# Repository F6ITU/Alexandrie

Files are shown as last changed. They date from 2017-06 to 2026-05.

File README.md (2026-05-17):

# Alexandrie

  **Pour plus d'informations, consultez le Wiki associé à cette page**
  **For more information, see the Wiki associated with this page**
  
Kicad files

Control board for Alexiares filter set

This work is protected by the TAPR Open Hardware Licence https://www.tapr.org/ohl.html

Original work by Graham Haddock, KE9H and Phil Harman, VK6APH.

This board supports the SPI "Alexiares" protocol (also called "J16") of 
the original Hermes SDR board designed by the OpenHPSDR group.

As Alexiares was not sold anymore by the TAPR, a new and more "modular" 
design was needed by many hams wishing to play with OpenHPSDR plateforms
(Homebrewed Hermes or Angelia boards, Steve KF7O's Hermes Lite, Red Pitaya 
supporting Pavel Denim's firmware... ) 

Alexandrie is only needed by people using an original 
Hermes Board or a Red Pitaya (via the SPI output)

A specific replacement board (Alexi2C) has been design for 

* Hermes, Angelia, Odyssey2, HiQSDR boards
*  Red Pitaya owners using the I2C output

3D image of the board are stored on this repo

Alexandrie dwn.jpg

Alexandrie up.jpg

Board's dimensions are oversized to fit the 5x10 and 10x10cm 
size of all board of the Hermes project under Kicad: 

AlexI2C

Alexandrie (this one)

Alexiares_Coax_Out

Alexiares_HPF

Alexiares_LPF

Mentor

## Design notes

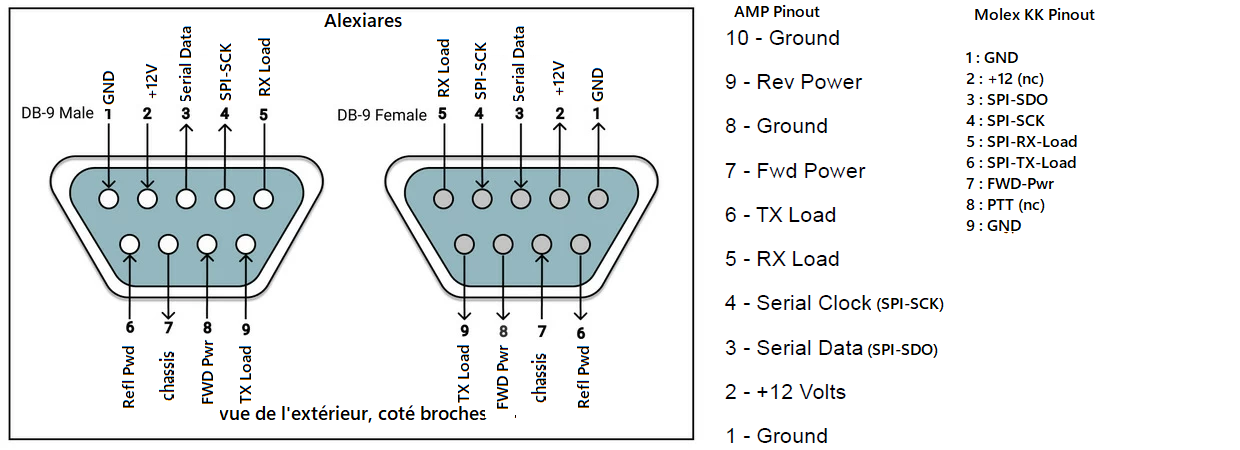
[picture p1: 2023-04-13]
Hermes-Alex_Pinout.png

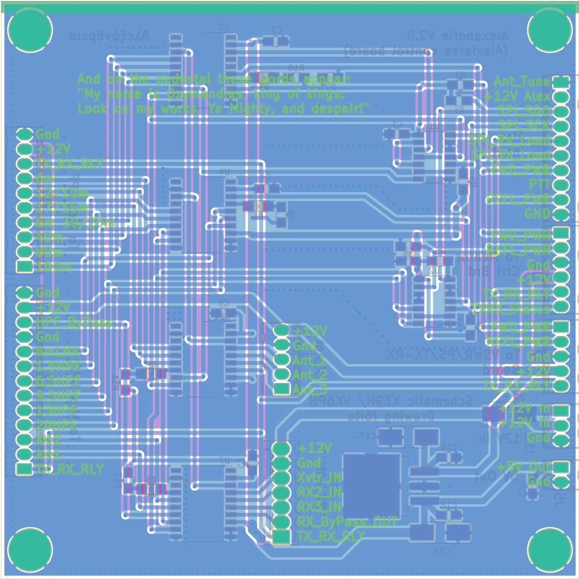
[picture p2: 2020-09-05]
Gerber.png_top_XRAY.png

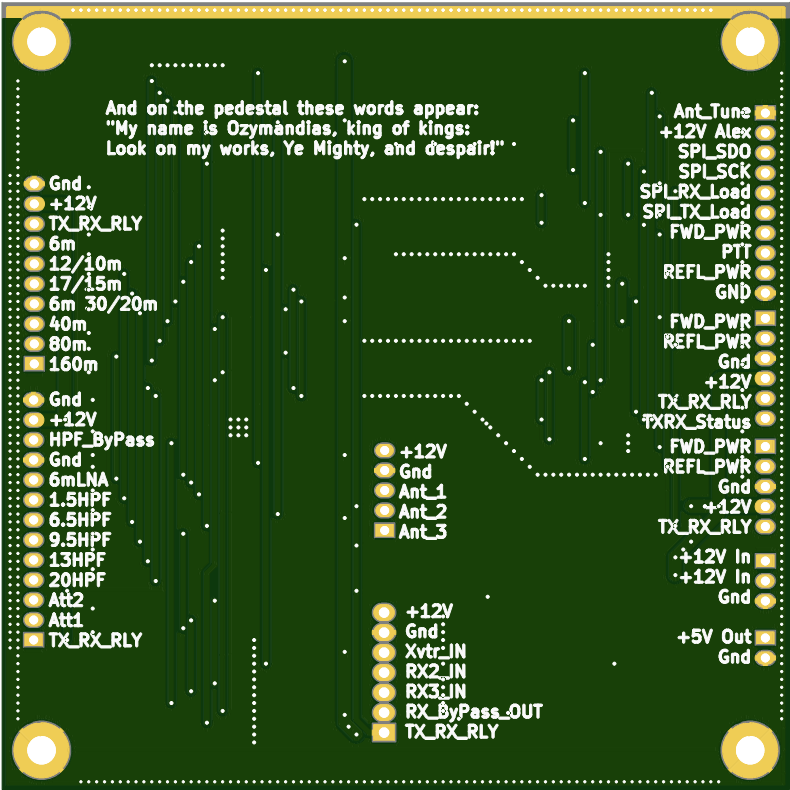
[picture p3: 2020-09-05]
Gerber.png_Combined_Bottom.png

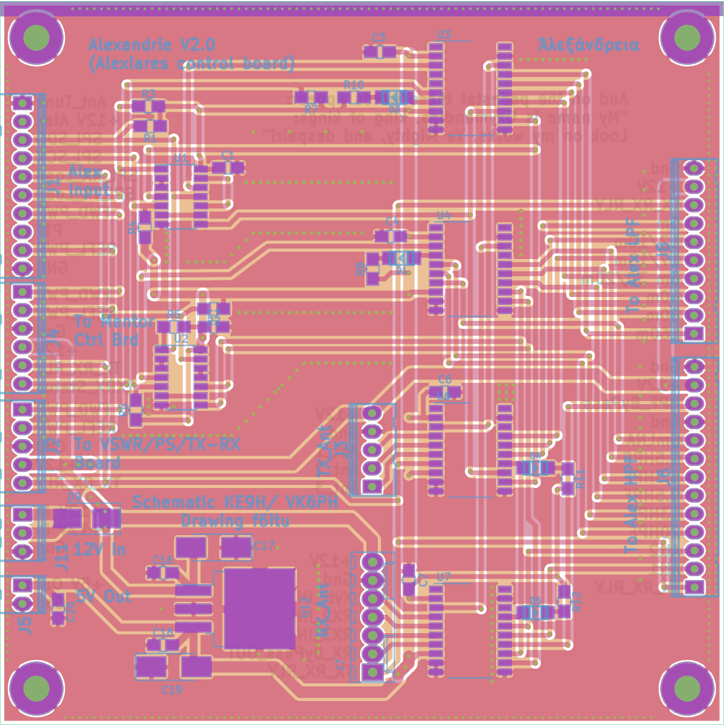
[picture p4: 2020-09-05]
Gerber.png_bottom_XRAY.png

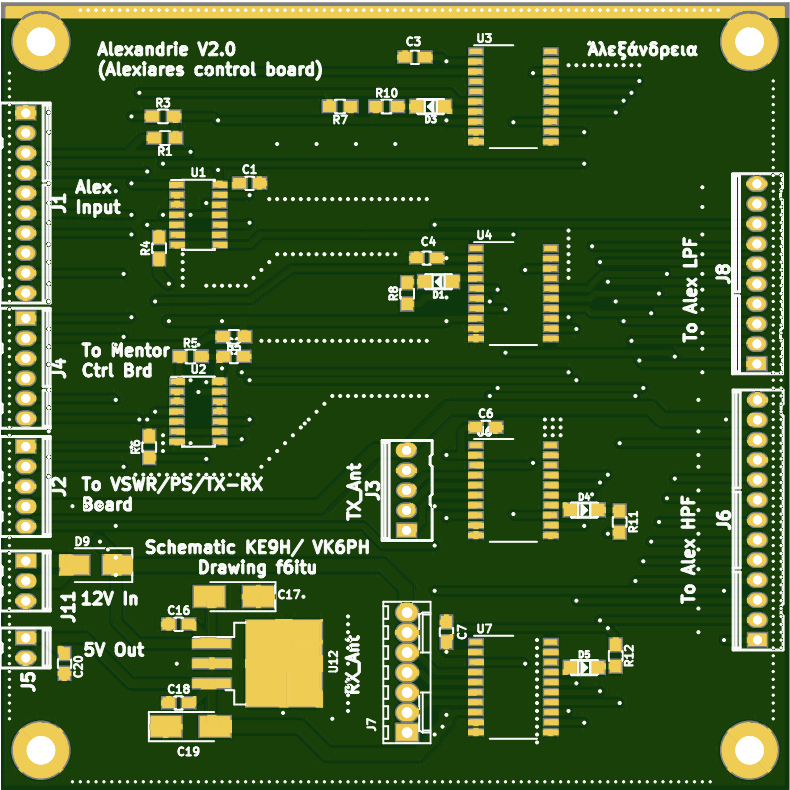
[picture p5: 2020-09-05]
Gerber.png_Combined_Top.png

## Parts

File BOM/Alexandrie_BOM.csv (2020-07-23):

Component Count: | 43
Ref | Value | Footprint | Manufacturer | Vendor | Reference
C1 | 100n | Capacitors_SMD:C_0805_HandSoldering
C2 | 100n | Capacitors_SMD:C_0805_HandSoldering
C3 | 100n | Capacitors_SMD:C_0805_HandSoldering
C4 | 100n | Capacitors_SMD:C_0805_HandSoldering
C6 | 100n | Capacitors_SMD:C_0805_HandSoldering
C7 | 100n | Capacitors_SMD:C_0805_HandSoldering
C16 | 100n | Capacitors_SMD:C_0805_HandSoldering
C17 | 10u | Capacitors_Tantalum_SMD Case-C_EIA-6032-28
C18 | 100n | Capacitors_SMD:C_0805_HandSoldering
C19 | 10u | Capacitors_Tantalum_SMD: Case-C_EIA-6032-28
C20 | 100n | Capacitors_SMD:C_0805_HandSoldering
D1 | LED | smd_leds:Led_1206
D3 | LED | smd_leds:Led_1206
D4 | LED | smd_leds:Led_1206
D5 | LED | smd_leds:Led_1206
D9 | D | Diodes_SMD:D_SMB_Handsoldering | On Semiconductor ss24 | Mouser | 863-SS24T3G
J1 | kk_10 | conn_kk100:kk100_22-23-2101 | Molex KF2510 | eBay | KF2510-10P
J2 | kk_5 | conn_kk100:kk100_22-23-2051 | Molex KF2510 | eBay | KF2510-5P
J3 | kk_5 | conn_kk100:kk100_22-23-2051 | Molex KF2510 | eBay | KF2510-5P
J4 | CONN_01X06 | conn_kk100:kk100_22-23-2061 | Molex KF2510 | eBay | KF2510-6P
J5 | CONN_01X02 | conn_kk100:kk100_22-23-2021 | Molex KF2510 | eBay | KF2510-2P
J6 | CONN_01X13 | conn_kk100:kk100_22-23-2131 | Molex KF2510 | eBay | KF2510-13P
J7 | Conn_01x07 | Connectors_Molex:Molex_KK-6410-07_07x2.54mm_Straight | Molex KF2510 | eBay | KF2510-7P
J8 | kk_10 | conn_kk100:kk100_22-23-2101 | Molex KF2510 | eBay | KF2510-10P
J11 | CONN_01X03 | conn_kk100:kk100_22-23-2031 | Molex KF2510 | eBay | KF2510-13P
R1 | 10k | Resistors_SMD:R_0805_HandSoldering
R2 | 10k | Resistors_SMD:R_0805_HandSoldering
R3 | 10k | Resistors_SMD:R_0805_HandSoldering
R4 | 10k | Resistors_SMD:R_0805_HandSoldering
R5 | 10k | Resistors_SMD:R_0805_HandSoldering
R6 | 10k | Resistors_SMD:R_0805_HandSoldering
R7 | 4k7 | Resistors_SMD:R_0805_HandSoldering
R8 | 1k2 | Resistors_SMD:R_0805_HandSoldering
R10 | 1k2 | Resistors_SMD:R_0805_HandSoldering
R11 | 1k2 | Resistors_SMD:R_0805_HandSoldering
R12 | 1k2 | Resistors_SMD:R_0805_HandSoldering
U1 | 74HCT04 | Housings_SOIC:SOIC-14_3.9x8.7mm_Pitch1.27mm |  | Mouser | MC74HCT04ADR2G
U2 | 74HCT04 | Housings_SOIC:SOIC-14_3.9x8.7mm_Pitch1.27mm |  | Mouser | MC74HCT04ADR2G
U3 | TPIC6B595 | Housings_SOIC:SO-20_12.8x7.5mm_Pitch1.27mm |  | Mouser | 595-TPIC6B595DWR
U4 | TPIC6B595 | Housings_SOIC:SO-20_12.8x7.5mm_Pitch1.27mm |  | Mouser | 595-TPIC6B595DWR
U6 | TPIC6B595 | Housings_SOIC:SO-20_12.8x7.5mm_Pitch1.27mm |  | Mouser | 595-TPIC6B595DWR
U7 | TPIC6B595 | Housings_SOIC:SO-20_12.8x7.5mm_Pitch1.27mm |  | Mouser | 595-TPIC6B595DWR
U12 | 78M05 Dpak | TO_SOT_Packages_SMD:TO-263-3_TabPin4 |  | Mouser | 863-NCV78M05BDTRKG
Les composants "ancilaires" (condensateurs de découplage, résistances,LED) ne nécessitent aucun précaution particulière

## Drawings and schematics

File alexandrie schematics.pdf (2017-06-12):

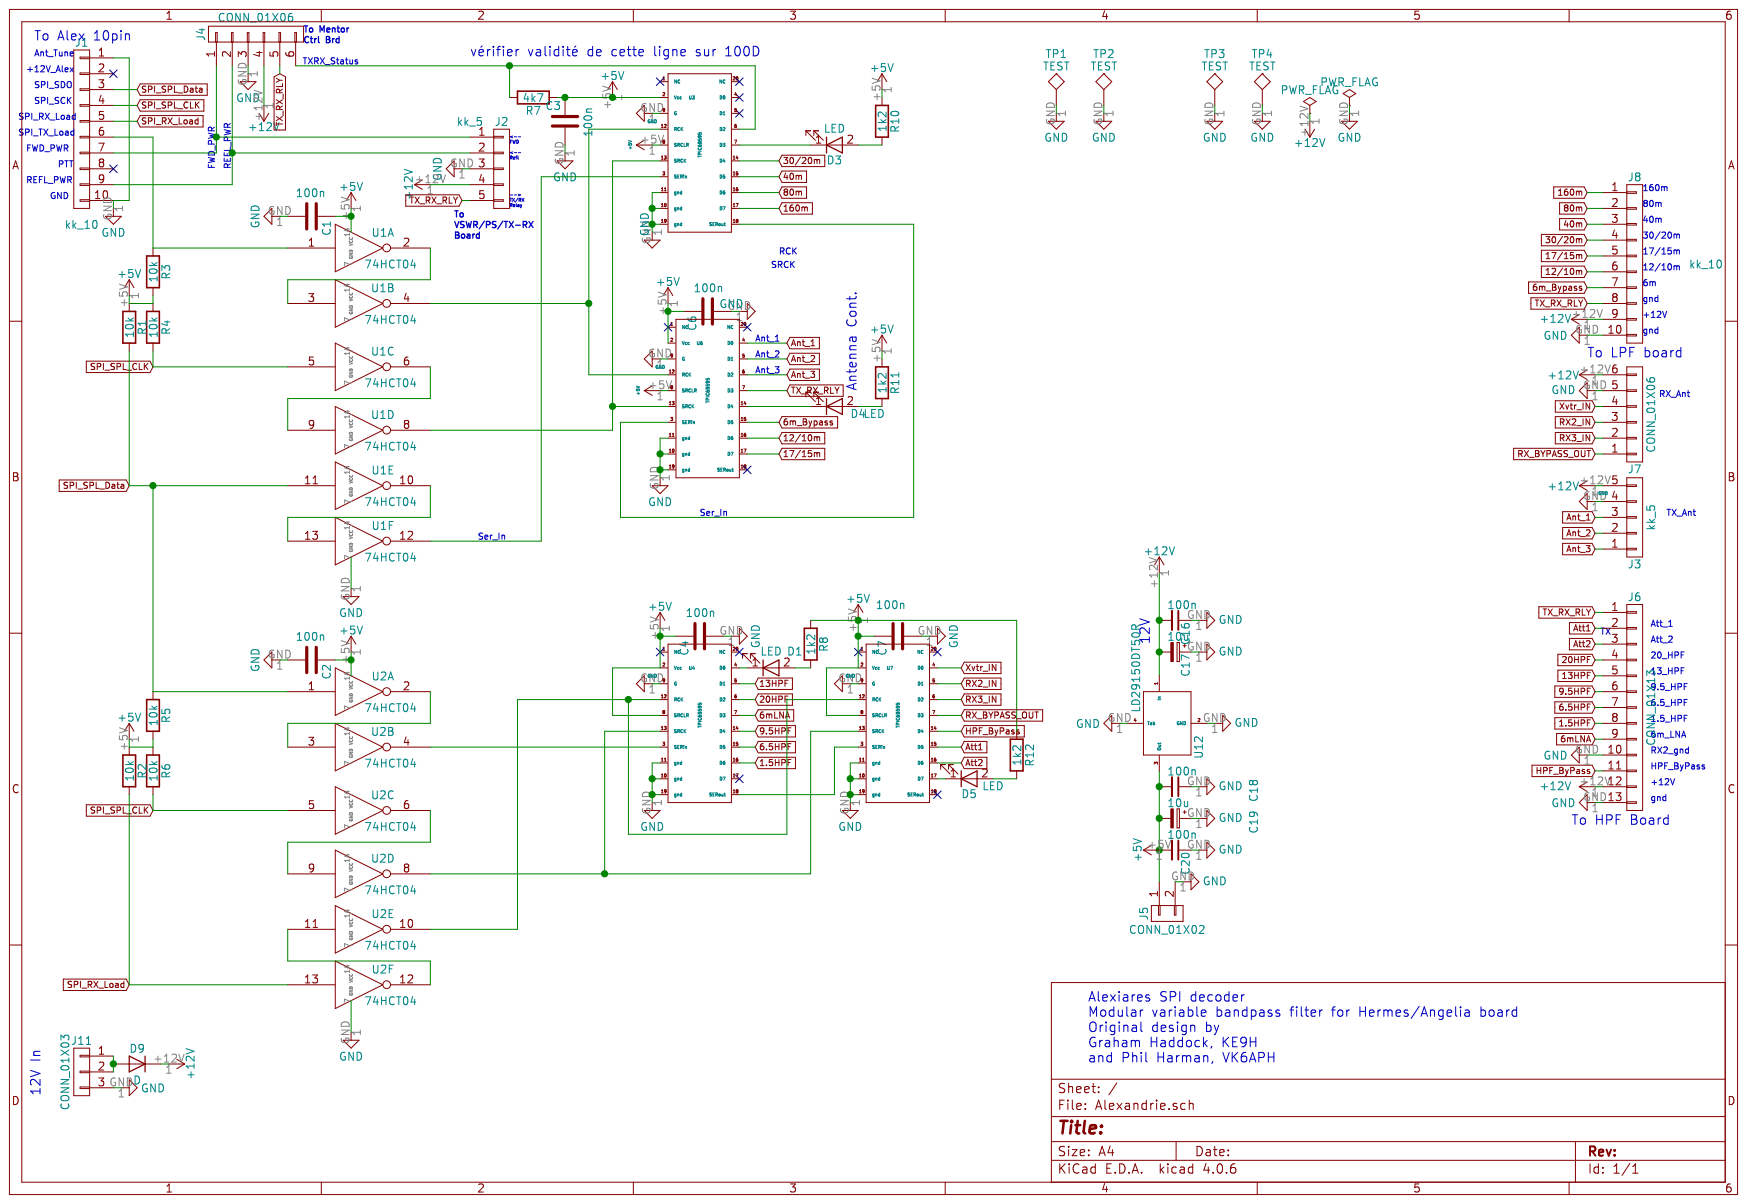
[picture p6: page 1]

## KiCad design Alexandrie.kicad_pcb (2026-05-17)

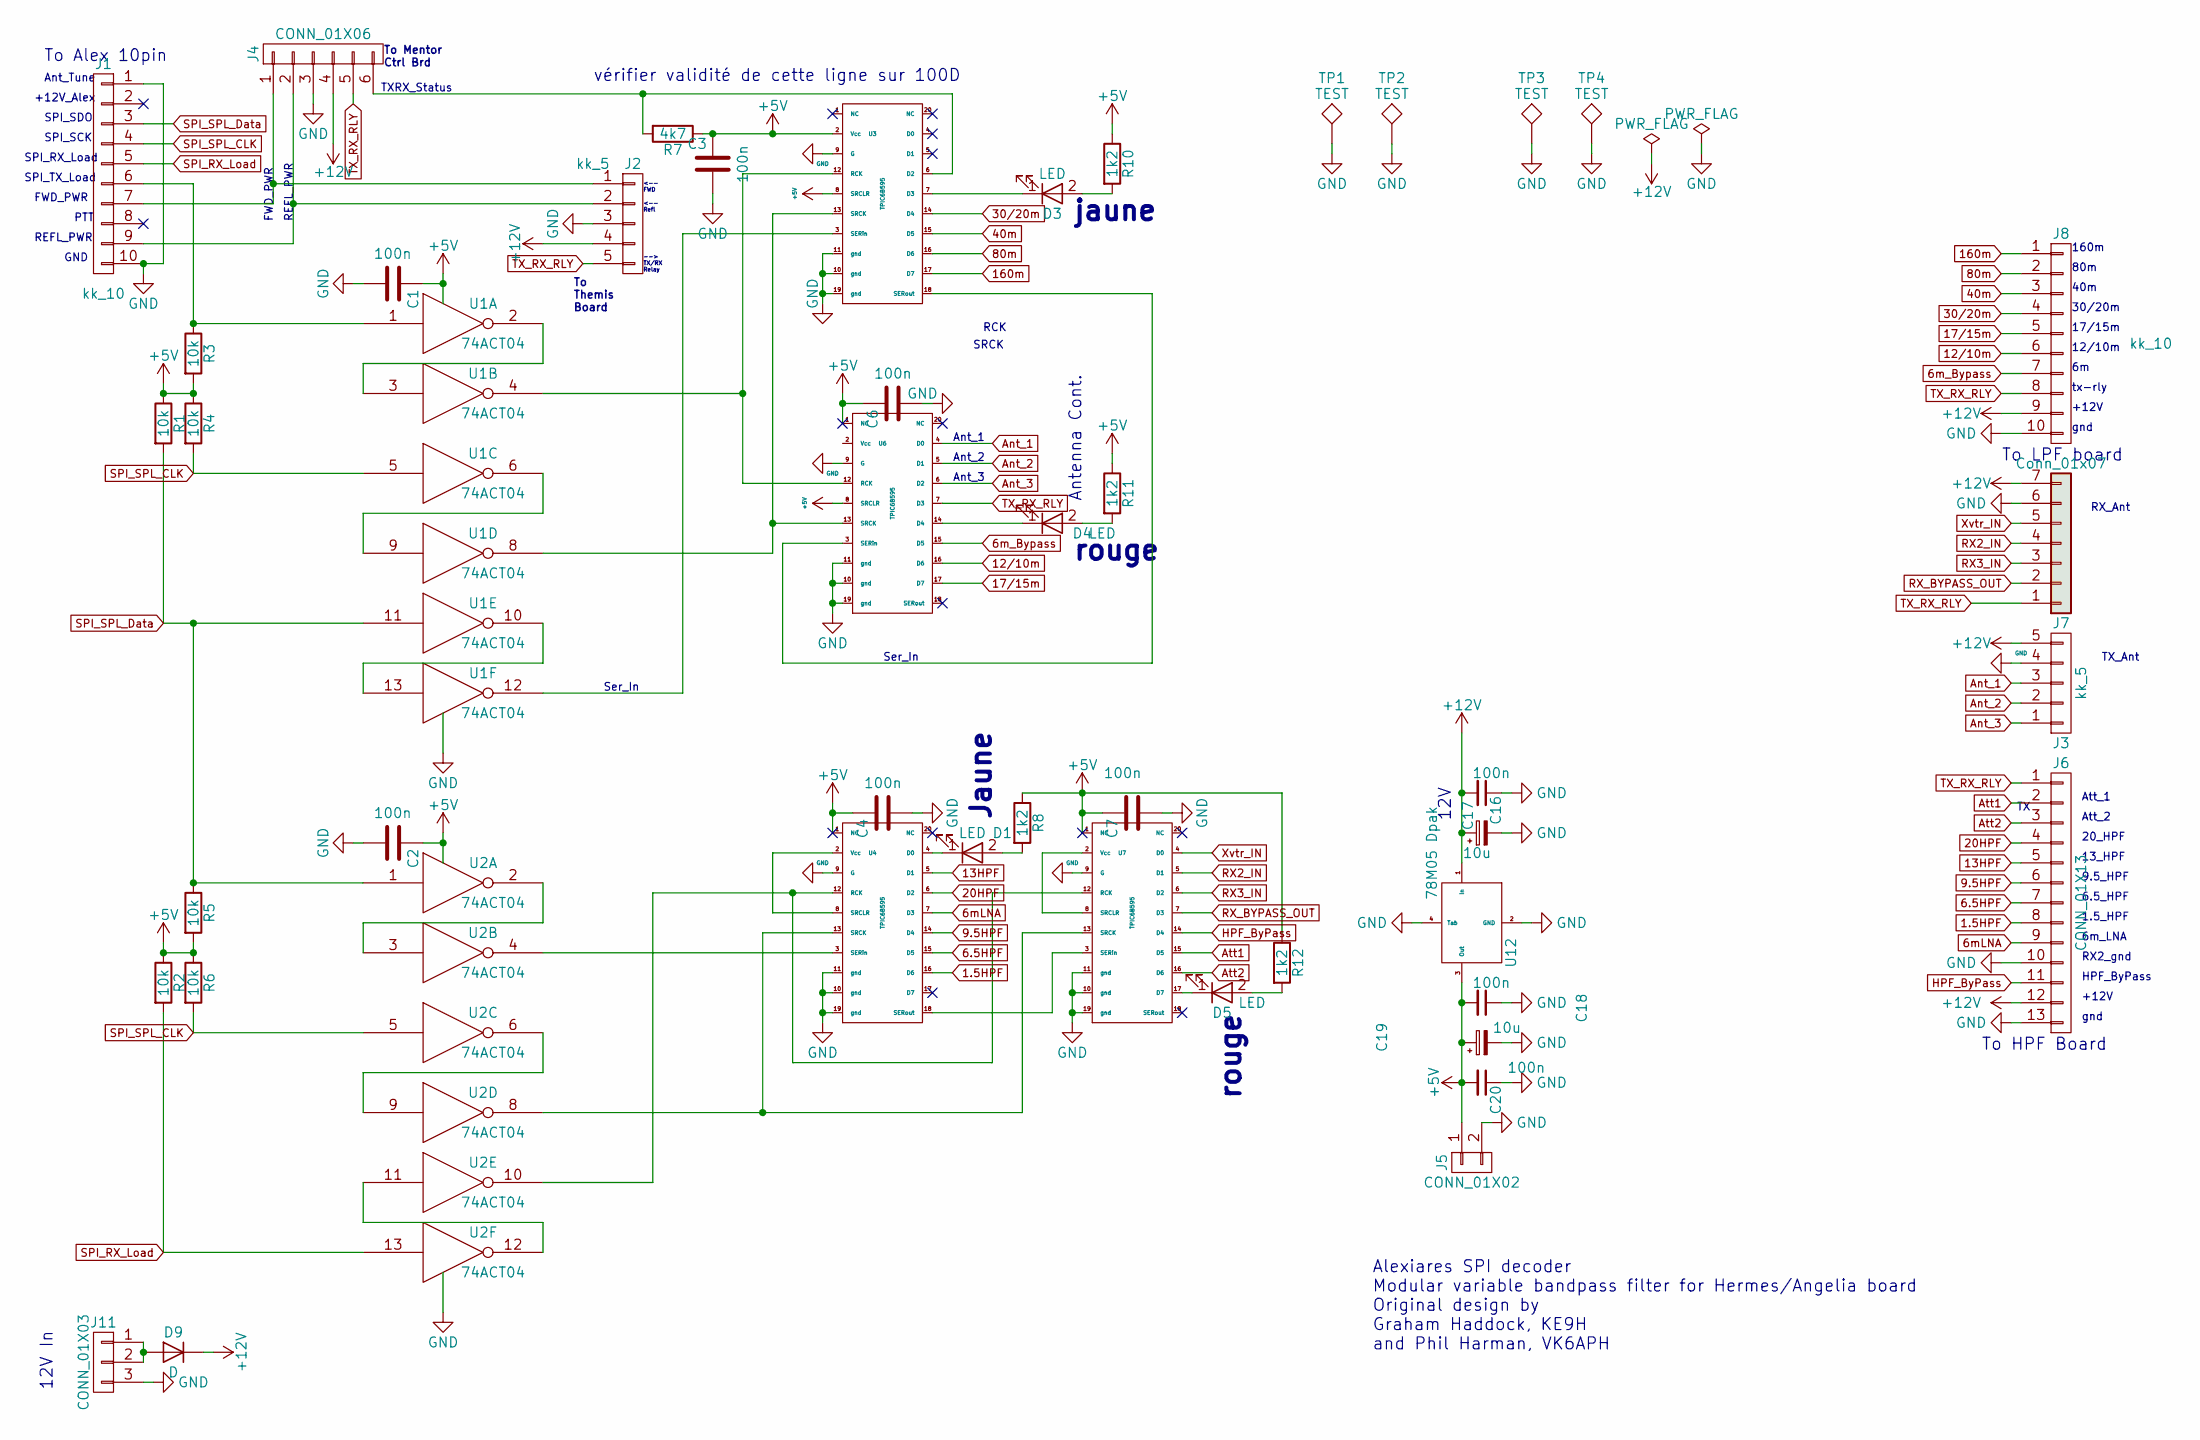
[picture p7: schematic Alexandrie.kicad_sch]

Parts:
C1, C2, C3, C4, C6, C7, C16, C18, C20: 100n; C_0805_2012Metric_Pad1.18x1.45mm_HandSolder
C17, C19: 10u; CP_Tantalum_Case-C_EIA-6032-28_Hand
D1, D3, D4, D5: LED; LED_1206_3216Metric_Pad1.42x1.75mm_HandSolder
D9: D; D_SMB_Handsoldering
J1, J8: kk_10; kk100_22-23-2101
J2, J3: kk_5; kk100_22-23-2051
J4: CONN_01X06; kk100_22-23-2061
J5: CONN_01X02; kk100_22-23-2021
J6: CONN_01X13; kk100_22-23-2131
J7: Conn_01x07; Molex_KK-6410-07_07x2.54mm_Straight
J11: CONN_01X03; kk100_22-23-2031
R1, R2, R3, R4, R5, R6: 10k; R_0805_2012Metric_Pad1.20x1.40mm_HandSolder
R7: 4k7; R_0805_2012Metric_Pad1.20x1.40mm_HandSolder
R8, R10, R11, R12: 1k2; R_0805_2012Metric_Pad1.20x1.40mm_HandSolder
TP1, TP2, TP3, TP4: TEST; MountingHole_3.5mm_Pad
U1, U2: 74ACT04; SO-14_3.9x8.65mm_P1.27mm
U3, U4, U6, U7: TPIC6B595; SO-20_12.8x7.5mm_P1.27mm
U12: 78M05 Dpak; TO-263-3_TabPin4

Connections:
1.5HPF: J6.8, U4.16 (D6)
6.5HPF: J6.7, U4.15 (D5)
6mLNA: J6.9, U4.7 (D3)
6m_Bypass: J8.7, U6.15 (D5)
9.5HPF: J6.6, U4.14 (D4)
12/10m: J8.6, U6.16 (D6)
13HPF: J6.5, U4.5 (D1)
17/15m: J8.5, U6.17 (D7)
20HPF: J6.4, U4.6 (D2)
30/20m: J8.4, U3.14 (D4)
40m: J8.3, U3.15 (D5)
80m: J8.2, U3.16 (D6)
160m: J8.1, U3.17 (D7)
+5V: C1.1, C2.1, C3.1, C4.1, C6.1, C7.1, C18.2, C19.1, C20.2, J5.1, R1.1, R2.1, R3.2, R4.1, R5.2, R6.1, R7.1, R8.1, R10.1, R11.1, R12.1, U1.14 (VCC), U2.14 (VCC), U3.2 (Vcc), U3.8 (SRCLR), U4.1 (NC), U6.1 (NC), U6.8 (SRCLR), U7.1 (NC), U12.3 (Out)
+12V: C16.2, C17.1, D9.1 (K), J2.4, J3.5, J4.4, J6.12, J7.7, J8.9, U12.1 (In)
Ant_1: J3.3, U6.4 (D0)
Ant_2: J3.2, U6.5 (D1)
Ant_3: J3.1, U6.6 (D2)
Att1: J6.2, U7.15 (D5)
Att2: J6.3, U7.16 (D6)
GND: C1.2, C2.2, C3.2, C4.2, C6.2, C7.2, C16.1, C17.2, C18.1, C19.2, C20.1, J1.1, J1.10, J2.3, J3.4, J4.3, J5.2, J6.10, J6.13, J7.6, J8.10, J11.3, TP1.1, TP2.1, TP3.1, TP4.1, U1.7 (GND), U2.7 (GND), U3.9 (G), U3.10 (gnd), U3.11 (gnd), U3.19 (gnd), U4.9 (G), U4.10 (gnd), U4.11 (gnd), U4.19 (gnd), U6.9 (G), U6.10 (gnd), U6.11 (gnd), U6.19 (gnd), U7.9 (G), U7.10 (gnd), U7.11 (gnd), U7.19 (gnd), U12.2 (GND), U12.4 (Tab)
HPF_ByPass: J6.11, U7.14 (D4)
unnamed: D1.1 (K), U4.4 (D0)
unnamed: D1.2 (A), R8.2
unnamed: D3.1 (K), U3.7 (D3)
unnamed: D3.2 (A), R10.2
unnamed: D4.1 (K), U6.14 (D4)
unnamed: D4.2 (A), R11.2
unnamed: D5.1 (K), U7.17 (D7)
unnamed: D5.2 (A), R12.2
unnamed: D9.2 (A), J11.1, J11.2
unnamed: J1.6, R3.1, U1.1
unnamed: J1.7, J2.1, J4.1
unnamed: J1.9, J2.2, J4.2
unnamed: J4.6, R7.2, U3.6 (D2)
unnamed: U1.2, U1.3
unnamed: U1.4, U3.12 (RCK), U6.12 (RCK)
unnamed: U1.6, U1.9
unnamed: U1.8, U3.13 (SRCK), U6.13 (SRCK)
unnamed: U1.10, U1.13
unnamed: U1.12, U3.3 (SERin)
unnamed: U2.2, U2.3
unnamed: U2.4, U4.3 (SERin)
unnamed: U2.6, U2.9
unnamed: U2.8, U4.13 (SRCK), U7.13 (SRCK)
unnamed: U2.10, U4.12 (RCK), U7.12 (RCK)
unnamed: U2.11, U2.12
unnamed: U3.18 (SERout), U6.3 (SERin)
unnamed: U4.2 (Vcc), U4.8 (SRCLR)
unnamed: U4.18 (SERout), U7.3 (SERin)
unnamed: U7.2 (Vcc), U7.8 (SRCLR)
RX2_IN: J7.4, U7.5 (D1)
RX3_IN: J7.3, U7.6 (D2)
RX_BYPASS_OUT: J7.2, U7.7 (D3)
SPI_RX_Load: J1.5, R2.2, U2.13
SPI_SPL_CLK: J1.4, R4.2, R6.2, U1.5, U2.5
SPI_SPL_Data: J1.3, R1.2, R5.1, U1.11, U2.1
TX_RX_RLY: J2.5, J4.5, J6.1, J7.1, J8.8, U6.7 (D3)
Xvtr_IN: J7.5, U7.4 (D0)

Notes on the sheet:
20_HPF
SRCK
SPI_SDO
To HPF Board
160m
FWD_PWR
Jaune
17/15m
PTT
6.5_HPF
Ant_1
Antenna Cont.
1.5_HPF
SPI_SCK
<-- Refl
tx-rly
Ant_3
REFL_PWR
jaune
9.5_HPF
80m
TXRX_Status
To Themis Board
<-- FWD
6m_LNA
Att_1
To Alex 10pin
gnd
12/10m
RCK
--> TX/RX Relay
30/20m
Ser_In
RX_Ant
GND
Alexiares SPI decoder Modular variable bandpass filter for Hermes/Angelia board Original design by Graham Haddock, KE9H and Phil Harman, VK6APH
rouge
Ant_Tune
RX2_gnd
40m

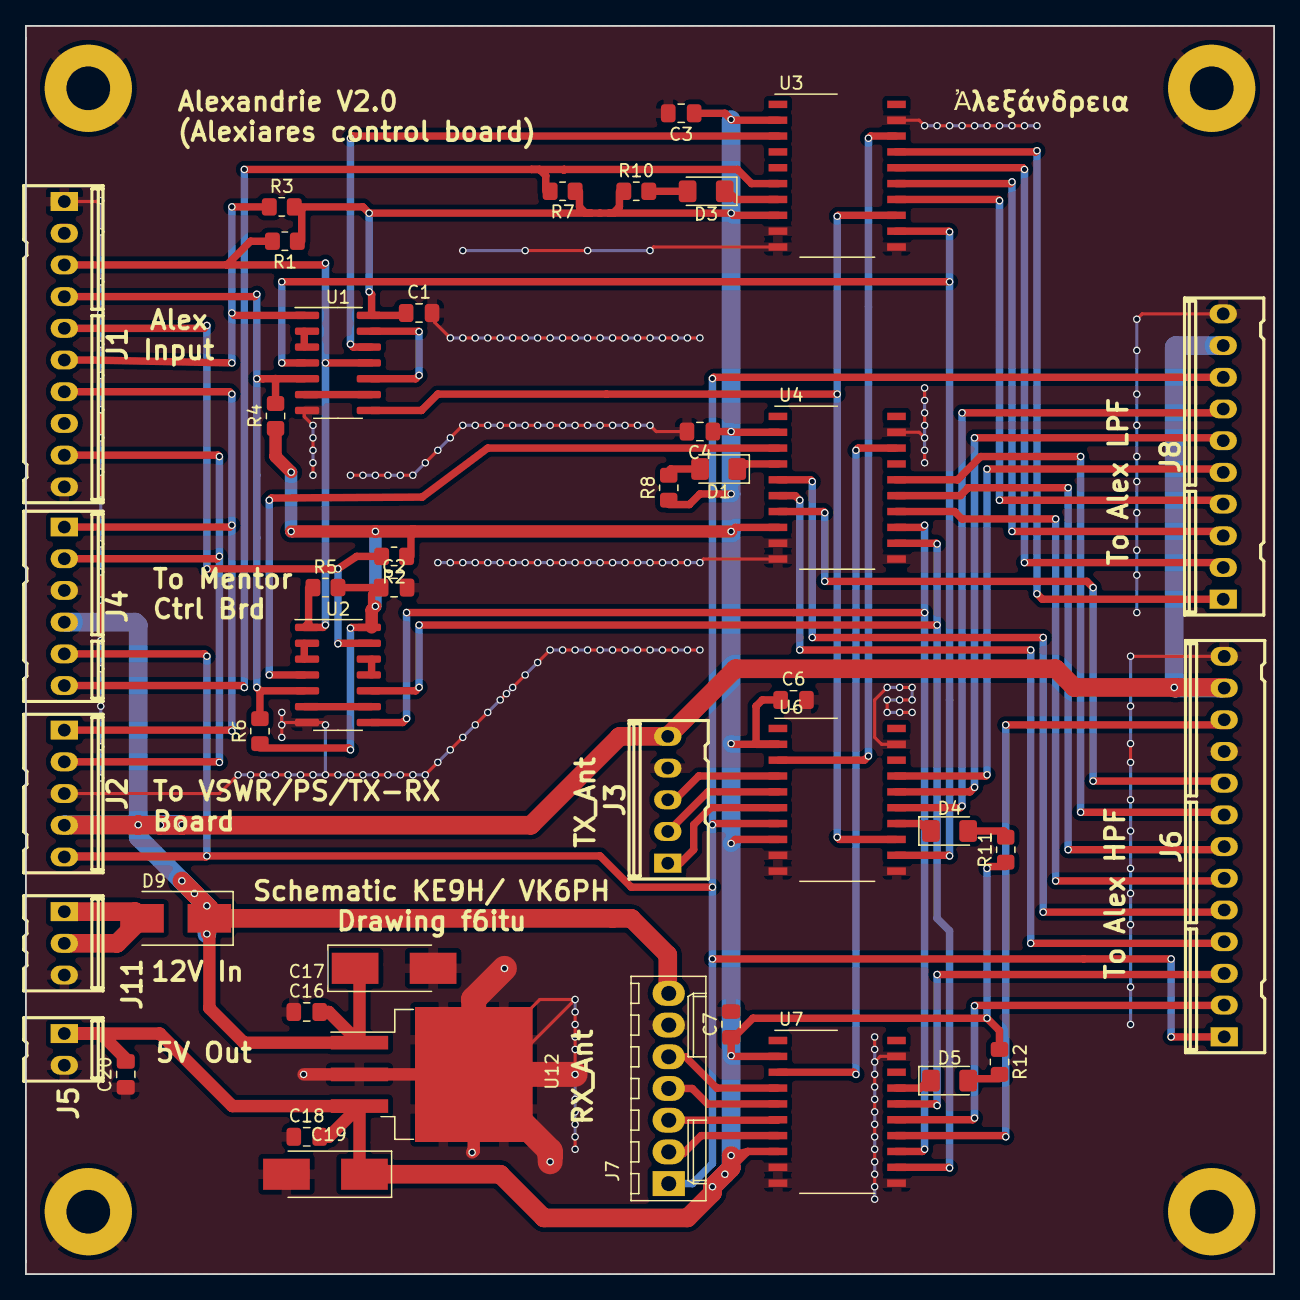
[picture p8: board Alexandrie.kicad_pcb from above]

Board: 2 copper layers, 100.0 x 100.0 mm, 47 parts (0 on the bottom side), 59 nets.

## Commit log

2017-05-23 schematic without power regulators
    [Alexandrie.kicad_pcb, Alexandrie.sch]
2017-05-23 Angelia lpf/hpf Control board
    [Alexandrie.sch]
2017-05-25 final schematic drawing
    [Alexandrie.sch]
2017-05-27 minor schematic errors fixed
    [Alexandrie.sch]
2017-05-28 Alexandrie V 1.0 pcb routing w/o power supply
    [Alexandrie.sch]
2017-05-29 final beta, Sylkmask to annotate
    [Alexandrie.kicad_pcb, Alexandrie.sch]
2017-05-31 RTM with sylkmask
    [Alexandrie.kicad_pcb, Alexandrie.sch]
2017-06-12 Complete redrawing, Alexiares compatible
    [Alexandrie.kicad_pcb, Alexandrie.sch]
2017-10-03 some minor cleaning
    [Alexandrie.kicad_pcb]
2017-11-01 RTM 1
    [Alexandrie.kicad_pcb]
2017-11-02 Silk Screen errors fixed
    [Alexandrie.kicad_pcb]
2017-11-02 Readme cleaning, add 2 3D pictures
    [Alexandrie.kicad_pcb]
2017-11-27 new footprint for drivers
    [Alexandrie.kicad_pcb, Alexandrie.sch]
2017-12-30 minor changes, BOM added
    [Alexandrie.kicad_pcb, Alexandrie.sch, BOM Alexandrie.csv]
2017-12-30 Gerber files added
    [Alexandrie-B.Cu.gbl, Alexandrie-B.Mask.gbs, Alexandrie-B.SilkS.gbo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]
2018-01-05 via stitching added, new gerber
    [Alexandrie-B.Cu.gbl, Alexandrie-B.Mask.gbs, Alexandrie-B.SilkS.gbo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]
2018-01-13 silk cleaning
    [Alexandrie-B.Cu.gbl, Alexandrie-B.Mask.gbs, Alexandrie-B.SilkS.gbo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]
2018-01-21 new gerber, minor mods
    [Alexandrie-B.Cu.gbl, Alexandrie-B.Mask.gbs, Alexandrie-B.SilkS.gbo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]
2018-02-12 rx_bypass_out added on alexandrie
    [Alexandrie-B.Cu.gbl, Alexandrie-B.Mask.gbs, Alexandrie-B.SilkS.gbo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]
2018-02-12 hasl border added
    [Alexandrie.kicad_pcb]
2018-07-20 stable V2.0
    [Alexandrie.sch]
2019-03-15 upgrate to Kicad 5.0n, new up to date Gerber
    [Alexandrie-2019-03-14-08-09-51.sch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]
2020-07-23 cleaning, new bom and interactive bom
    [Alexandrie BOM.csv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]
2020-09-05 Gerber added
    [Alexandrie-B_Cu.dxf]
2023-04-13 last commit, project deprecated, replaced by AlexV2
    [Alexandrie-B_Cu.dxf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]
2026-05-17 kicad 10 update, new readme, new Wiki
    [Alexandrie.kicad_pcb, Alexandrie.kicad_sch]
